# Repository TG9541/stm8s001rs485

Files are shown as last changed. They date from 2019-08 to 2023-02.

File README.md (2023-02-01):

# A small STM8S001 Break-Out Board with RS485 and DS1621S Thermometer



This KiCad project provides a small PCB with an STM8S001J3M3, a RS485 interface and a DS1621S temperature sensor. Applications include [MODBUS with STM8 eForth](https://github.com/TG9541/stm8ef-modbus).

Here is a photo of an assembled board, together with the [RS485-CH340E dongle](https://github.com/TG9541/rs485-ch340e):

STM8S001J3 RS485 assembled

The STM8S001J3M3 is a member of the "STM8S Low Density" family that's based on the "STM8S Access Line" cross-breed STM8S903, which, compared with the STM8S003, has some ([undocumented](https://github.com/TG9541/stm8ef/wiki/STM8-Low-Density-Devices#stm8s001j3)) features.

The board is supported by [STM8 eForth](https://github.com/TG9541/stm8ef/) which means that it runs an interactive development system on the chip: the serial interface for the console can either use RS485, or a two-wire interface on the GPIO PC5.

A µC with merrily 5 GPIO pins is a good shield against feature creep, but the following things "had" to be included:

* most GPIOs, including the I2C bus (PB4 & PB5), and an analog input or timer output (PC5) and the are available on 6 pin header
* a narrow PCB for a cylindrical sensors with a diameter of 7mm
* 5V nominal supply, internal 3.3V power supply with an LDO regulator
* signalling LEDs for RS485 activity (RxTx) and direction (Tx)
* 120R termination optional 

Care should be taken not to exceed 6V input supply voltage. The internal 3.3V power supply is accssible on header pin J2.1 - according to the XC6206 datasheet the maximum current is 150mA.

## Design

The design is simple: The STM8S001J3 controls the direction of the SP3485 RS485 transceivr with PA1/PD6. R3 makes sure that the SWIM interface is still usable when the SP3485 is in receive mode (i.e. listening for RS485 communication).

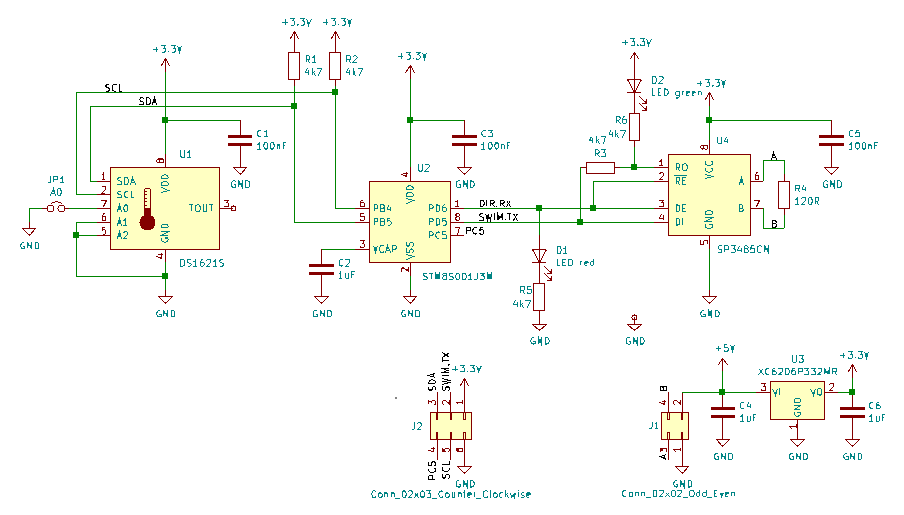
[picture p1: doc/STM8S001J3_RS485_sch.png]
STM8S001J3 RS485 schematics


LED D1 indicates RS485 communcation direction "transmit". LED D2 pulsing indecates bus activity in both directions where bright pulses indicates "read" and dim pulses "write". R4 is the (optional) RS485 termination resistor.

The BOM is in the docs folder.

## Pin Headers

Pin headers are also optional: they allow the board to be used as a module for quickly building a MODBUS node with a "perfboard" (using I2C or GPIOs), but connecting wires directly is also an intended use case.

### Description Header J1
Pin|Signal
-|-
1|3.4 to 6V for XC6206 3.3V LDO regulator
2|GND
3|RS485 "A"
4|RS485 "B"

### Description Header J2
Pin|Tag|Pin STM8S001|GPIO|Features
-|-|-|-|-
1|3.3|4|VDD|3.3V from LDO regulator
2||8|PC6 | SPI_MOSI, [TIM1_CH1]
2|SWIM|8|PD1 | **SWIM**
2||8|PD3 | TIM2_CH2, TIM2_CH2, ADC_ETR
2||8|PD5 | **UART1_TX**, AIN5
3||5|PA3 | TIM2_CH3, [SPI_NSS], [UART1_TX]
3|SDA|5|PB5 | **I2C_SDA**
4||7|PC3 | TIM1_CH3, [TLI], [TIM1_CH1N]
4||7|PC4 | TIM1_CH4, CLK_CCO, AIN2, [TIM1_CH3]
4|PC5|7|PC5 | SPI_SCK, [TIM2_CH1]
5|SCL|6|PB4 | **I2C_SCL**, [ADC_ETR]
6|GND|2|VSS|GND

## PCB and Assembly

Components occupy both sides of a PCB of 33.4mm x 1/4" (the minimal width supported by Oshpark).

On the front side there is the STM8S001J3M3, a XC6206 3.3V LDO regulator, some passive components, and the RS485 signalling LEDs:

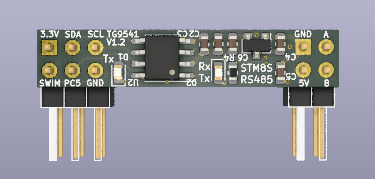
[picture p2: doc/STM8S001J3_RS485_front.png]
STM8S001J3 RS485 front


A generic 3.3V RS485 transceiver (like SP3485 or MAX3485l) and the (optional) DS1621S thermometer chip are on the backside:

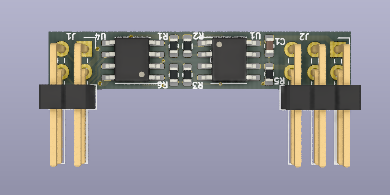
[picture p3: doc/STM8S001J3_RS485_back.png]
STM8S001J3 RS485 back


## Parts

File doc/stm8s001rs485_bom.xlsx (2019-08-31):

Source: | /home/thomas/kicad/stm8s001rs485/stm8s001rs485.sch
Date: | Sa 31 Aug 2019 14:30:23 CEST
Tool: | Eeschema 5.1.4-e60b266~84~ubuntu16.04.1
Generator: | /usr/share/kicad/plugins/bom_csv_grouped_by_value_with_fp.py
Component Count: | 20
Ref | Qnty | Value | Cmp name | Footprint | Description | Vendor
C2, C4, C6, | 3 | 1uF | C | Capacitor_SMD:C_0603_1608Metric | Unpolarized capacitor
C3, C1, C5, | 3 | 100nF | C | Capacitor_SMD:C_0603_1608Metric | Unpolarized capacitor
D1, | 1 | LED red | LED | LED_SMD:LED_0603_1608Metric | Light emitting diode
D2, | 1 | LED green | LED | LED_SMD:LED_0603_1608Metric | Light emitting diode
J1, | 1 | Conn_02x02_Odd_Even | Conn_02x02_Odd_Even | Connector_PinHeader_2.54mm:PinHeader_2x02_P2.54mm_Horizontal | Generic connector, double row, 02x02, odd/even pin numbering scheme (row 1 odd numbers, row 2 even numbers), script generated (kicad-library-utils/schlib/autogen/connector/)
J2, | 1 | Conn_02x03_Counter_Clockwise | Conn_02x03_Counter_Clockwise | Connector_PinHeader_2.54mm:PinHeader_2x03_P2.54mm_Horizontal | Generic connector, double row, 02x03, counter clockwise pin numbering scheme (similar to DIP packge numbering), script generated (kicad-library-utils/schlib/autogen/connector/)
R1, R2, R5, R6, R3, | 5 | 4k7 | R | Resistor_SMD:R_0603_1608Metric | Resistor
R4, | 1 | 120R | R | Resistor_SMD:R_0603_1608Metric | Resistor
U1, | 1 | DS1621S | DS1621S | Package_SO:SOIC-8_3.9x4.9mm_P1.27mm | 1-Wire Digital Thermometer and Thermostat, SOIC-8
U2, | 1 | STM8S001J3M | STM8S001J3M | Package_SO:SOIC-8_3.9x4.9mm_P1.27mm | 16MHz, 8K Flash, 1K RAM, 128 EEPROM, SO-8
U3, | 1 | XC6206P332MR | XC6206P332MR | Package_TO_SOT_SMD:SOT-23 | Low Quiescent Current LDO Regulator, 3.3V, 200 mA, Vin<=7V, SOT-23
U4, | 1 | SP3485CN | SP3485CN | Package_SO:SOIC-8_3.9x4.9mm_P1.27mm | 3.3V Low Power Half-Duplex RS-485 Transceiver 10Mbps, SO8

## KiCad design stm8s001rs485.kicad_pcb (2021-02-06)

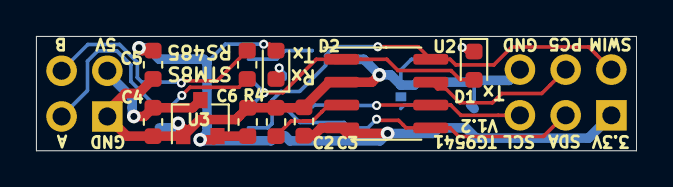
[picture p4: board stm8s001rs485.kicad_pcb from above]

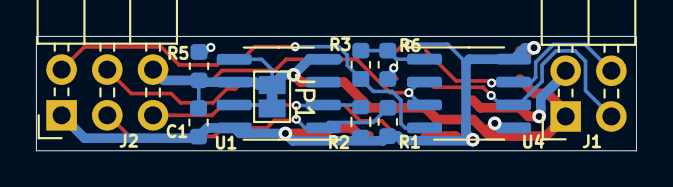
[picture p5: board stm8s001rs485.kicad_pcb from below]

Board: 2 copper layers, 33.3 x 6.3 mm, 21 parts (11 on the bottom side), 15 nets.

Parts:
C1, C3, C5: 100nF; C_0603_1608Metric
C2, C4, C6: 1uF; C_0603_1608Metric
D1: LED red; LED_0603_1608Metric
D2: LED green; LED_0603_1608Metric
J1: Conn_02x02_Odd_Even; PinHeader_2x02_P2.54mm_Horizontal
J2: Conn_02x03_Counter_Clockwise; PinHeader_2x03_P2.54mm_Horizontal
JP1: A0; SolderJumper-2_P1.3mm_Bridged_Pad1.0x1.5mm
R1, R2, R3, R5, R6: 4k7; R_0603_1608Metric
R4: 120R; R_0603_1608Metric
U1: DS1621S; SOIC-8_3.9x4.9mm_P1.27mm
U2: STM8S001J3M; SOIC-8_3.9x4.9mm_P1.27mm
U3: XC6206P332MR; SOT-23
U4: SP3485CN; SOIC-8_3.9x4.9mm_P1.27mm

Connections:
+3V3: C1.2, C3.2, C5.2, C6.2, D2.2, J2.1, R1.1, R2.1, U1.8, U2.4, U3.2, U4.8
+5V: C4.2, J1.2, U3.3
/A: J1.3, R4.1, U4.6
/B: J1.4, R4.2, U4.7
/DIR.RX: D1.2, U2.1, U4.2, U4.3
/PC5: J2.4, U2.7
/SCL: J2.5, R2.2, U1.2, U2.6
/SDA: J2.3, R1.2, U1.1, U2.5
/SWIM.TX: J2.2, R3.1, U2.8, U4.4
GND: C1.1, C2.1, C3.1, C4.1, C5.1, C6.1, J1.1, J2.6, JP1.1, R5.2, U1.4, U1.5, U1.6, U2.2, U3.1, U4.5
unnamed: C2.2, U2.3
unnamed: D1.1, R5.1
unnamed: D2.1, R6.1
unnamed: JP1.2, U1.7
unnamed: R3.2, R6.2, U4.1

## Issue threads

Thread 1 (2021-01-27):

STM8S001RS485

niuyingxian, 2021-01-27:
Can the modbus rtu source code of this project be shared? Where did I find it? Thank you

TG9541, 2021-01-30:
I'm at it - the STM8 eForth core needs to be updated to 2.2.27.pre1 - and I'm at it.

TG9541, 2021-02-06:
The code has been published and I also updated the KiCad project (slightly cleaner layout, RX/TX LED no longer inverted)

Closed 2021-02-06.

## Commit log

2019-08-31 Files according to first Oshpark order
    [stm8s001rs485.kicad_pcb, stm8s001rs485.sch]
2019-08-31 BOM added
    [stm8s001rs485.sch, stm8s001rs485_bom.xlsx]
2019-10-11 Improved component placement
    [stm8s001rs485.kicad_pcb]
2019-10-13 Aligned 3.3V vias
    [stm8s001rs485.kicad_pcb]
2019-10-13 V1.1 improved component placement
    [stm8s001rs485.kicad_pcb]
2021-02-06 improved RX/TX LED
    [stm8s001rs485.kicad_pcb, stm8s001rs485.sch]
